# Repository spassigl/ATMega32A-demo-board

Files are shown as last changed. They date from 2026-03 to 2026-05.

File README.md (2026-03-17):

# ATMega32A demo board
An ATMega32A demo board with exposed GPIO pins, LEDs, tactile switches and a buzzer

## The project
This is a simple ATMega32A board that I used to test some ideas for a bigger project. 
It's a small factor pcb - 88x43mm - with the following features:
- ATMega32A clocked at 16MHz
- 4 layer stackup
- USB-C conneector for power and, with a booloader like urboot, for firmware updates and serial communication. 
- ISP 6-pin connector to flash bootloader or firmware (in case you don't want to use a booloader like urboot or optiboot)
- Power OR-ing - can have both ISP and USB connected
- All the unused GPIO pins are exposed via connectors on the side of the board
- Can use AREF for the ADC pins. AVCC connected via a low pass filter to reduce ADC noise
- SCL/SDA pull-up resistors can be enabled through solder jumpers
- Includes a buzzer, two LEDs, two tactile buttons
- Footprints are optimized for JLCPCB and "Basic" or "Preferred Extended" parts, to lower assembly costs

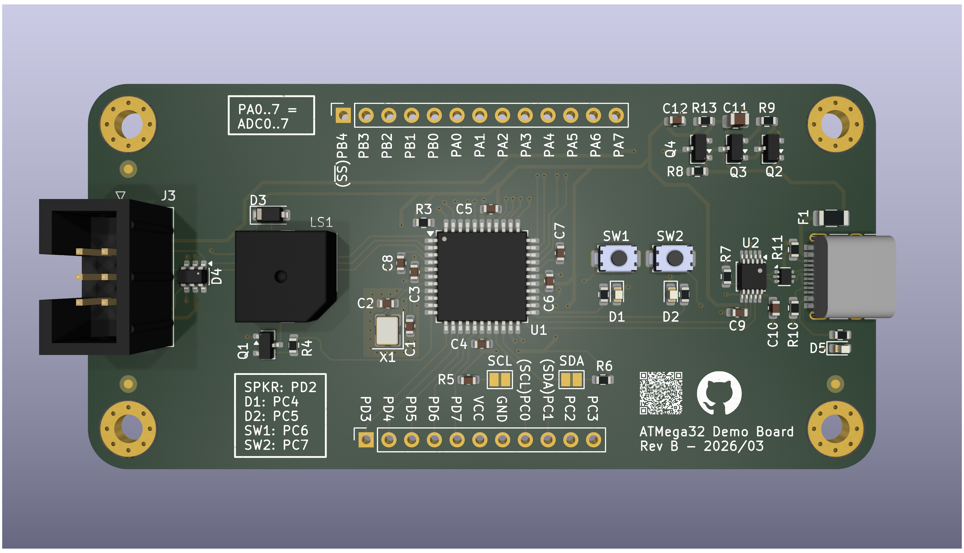
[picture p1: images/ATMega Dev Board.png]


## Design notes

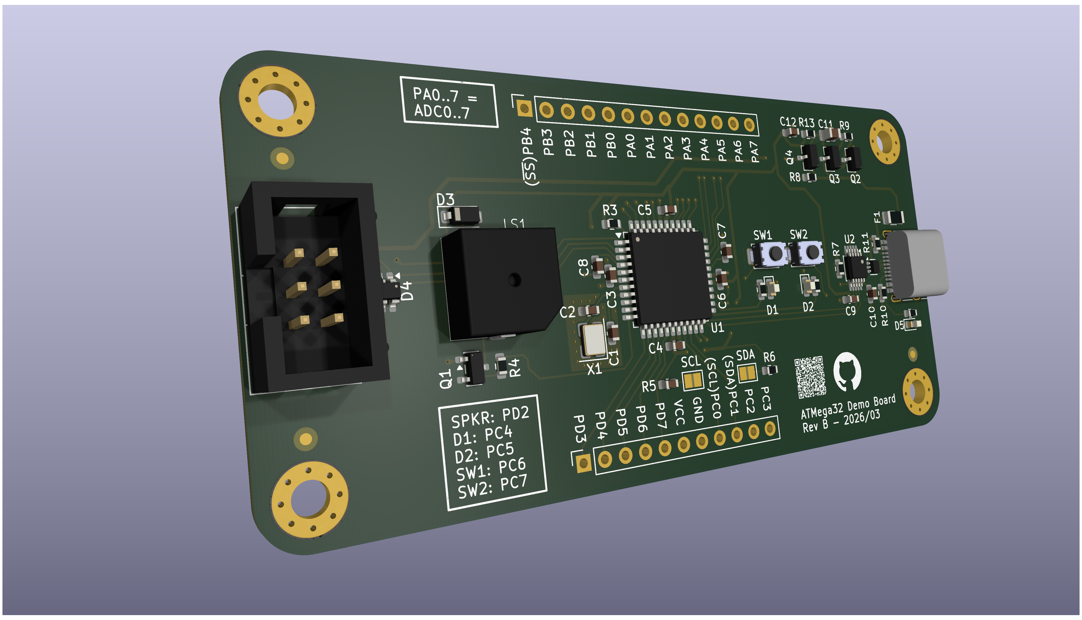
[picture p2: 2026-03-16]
images/ATMega Dev Board 3.png

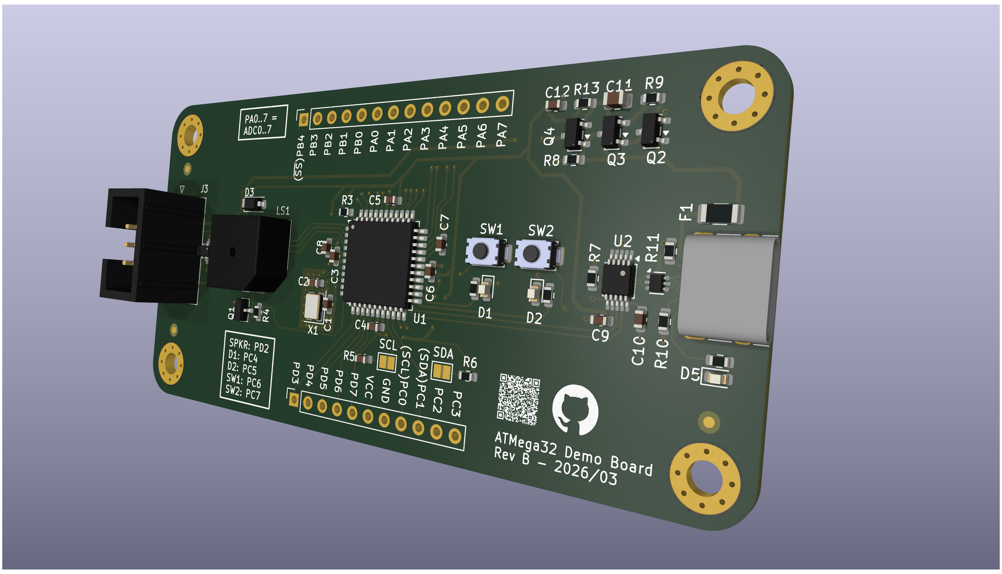
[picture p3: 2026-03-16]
images/ATMega Dev Board 2.png

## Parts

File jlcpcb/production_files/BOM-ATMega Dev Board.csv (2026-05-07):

Comment | Designator | Footprint | LCSC | Quantity
0.1u | C10,C12,C13,C3,C4,C5,C6,C7,C8,C9 | C_0603_1608Metric | C14663 | 10
0R | R13 | R_0603_1608Metric | C21189 | 1
10k | R3 | R_0603_1608Metric | C25804 | 1
10u | C11 | C_0805_2012Metric | C15850 | 1
10uH | L1 | L_0805_2012Metric | C2909263 | 1
16MHz | X1 | Crystal_SMD_3225-4Pin_3.2x2.5mm | C13738 | 1
1A | F1 | Fuse_1206_3216Metric | C69688 | 1
1N4001 | D3 | D_SOD-123 | C7462829 | 1
1k | R4 | R_0603_1608Metric | C21190 | 1
22p | C1,C2 | C_0603_1608Metric | C1653 | 2
2N7002 | Q2 | SOT-23 | C8545 | 1
330k | R8,R9 | R_0603_1608Metric | C23137 | 2
4k7 | R7 | R_0603_1608Metric | C23162 | 1
510 | R1,R12,R2 | R_0603_1608Metric | C23193 | 3
5k1 | R10,R11,R5,R6 | R_0603_1608Metric | C23186 | 4
ATmega32A-A | U1 | TQFP-44_10x10mm_P0.8mm | C5659 | 1
CH340X | U2 | MSOP-10_3x3mm_P0.5mm | C84681 | 1
HL6042 | Q3,Q4 | SOT-23 | C28646264 | 2
LED | D1,D2,D5 | LED_0603_1608Metric | C2286 | 3
S8050 | Q1 | SOT-23 | C2146 | 1
SPI header | J3 | IDC-Header_2x03_P2.54mm_Vertical | C492441 | 1
SRV05 | D4 | SOT-23-6 | C85364 | 1
SW_SPST | SW1,SW2 | Switch_TS-1088-AR02016 | C720477 | 2
Speaker | LS1 | Buzzer_MLT-9650 | C96127 | 1
USB-C_31-M-12 | J4 | USB_C_Receptacle_HRO_TYPE-C-31-M-12 | C165948 | 1
USBLC6-2P6 | U3 | SOT-666 | C15999 | 1

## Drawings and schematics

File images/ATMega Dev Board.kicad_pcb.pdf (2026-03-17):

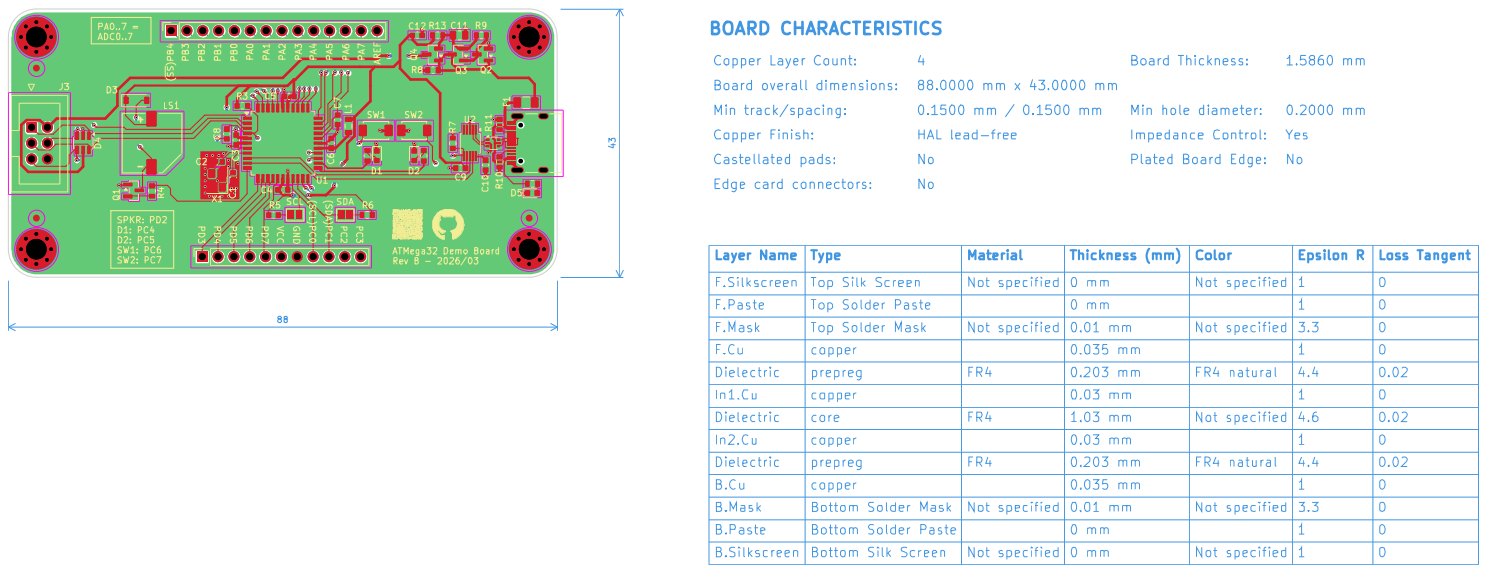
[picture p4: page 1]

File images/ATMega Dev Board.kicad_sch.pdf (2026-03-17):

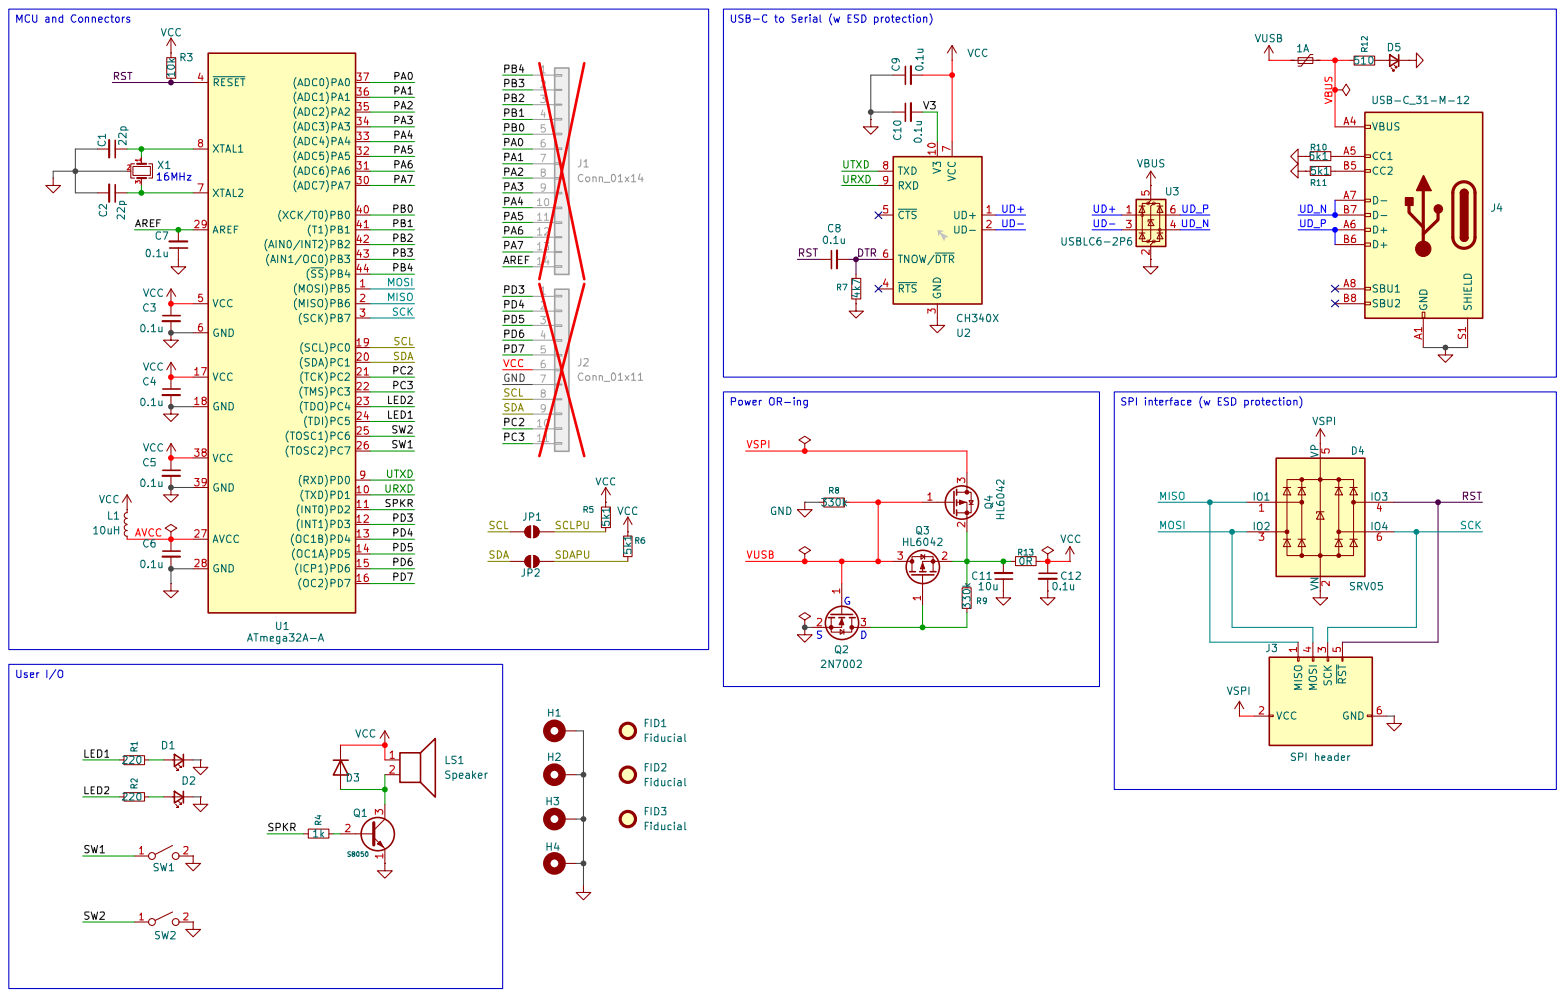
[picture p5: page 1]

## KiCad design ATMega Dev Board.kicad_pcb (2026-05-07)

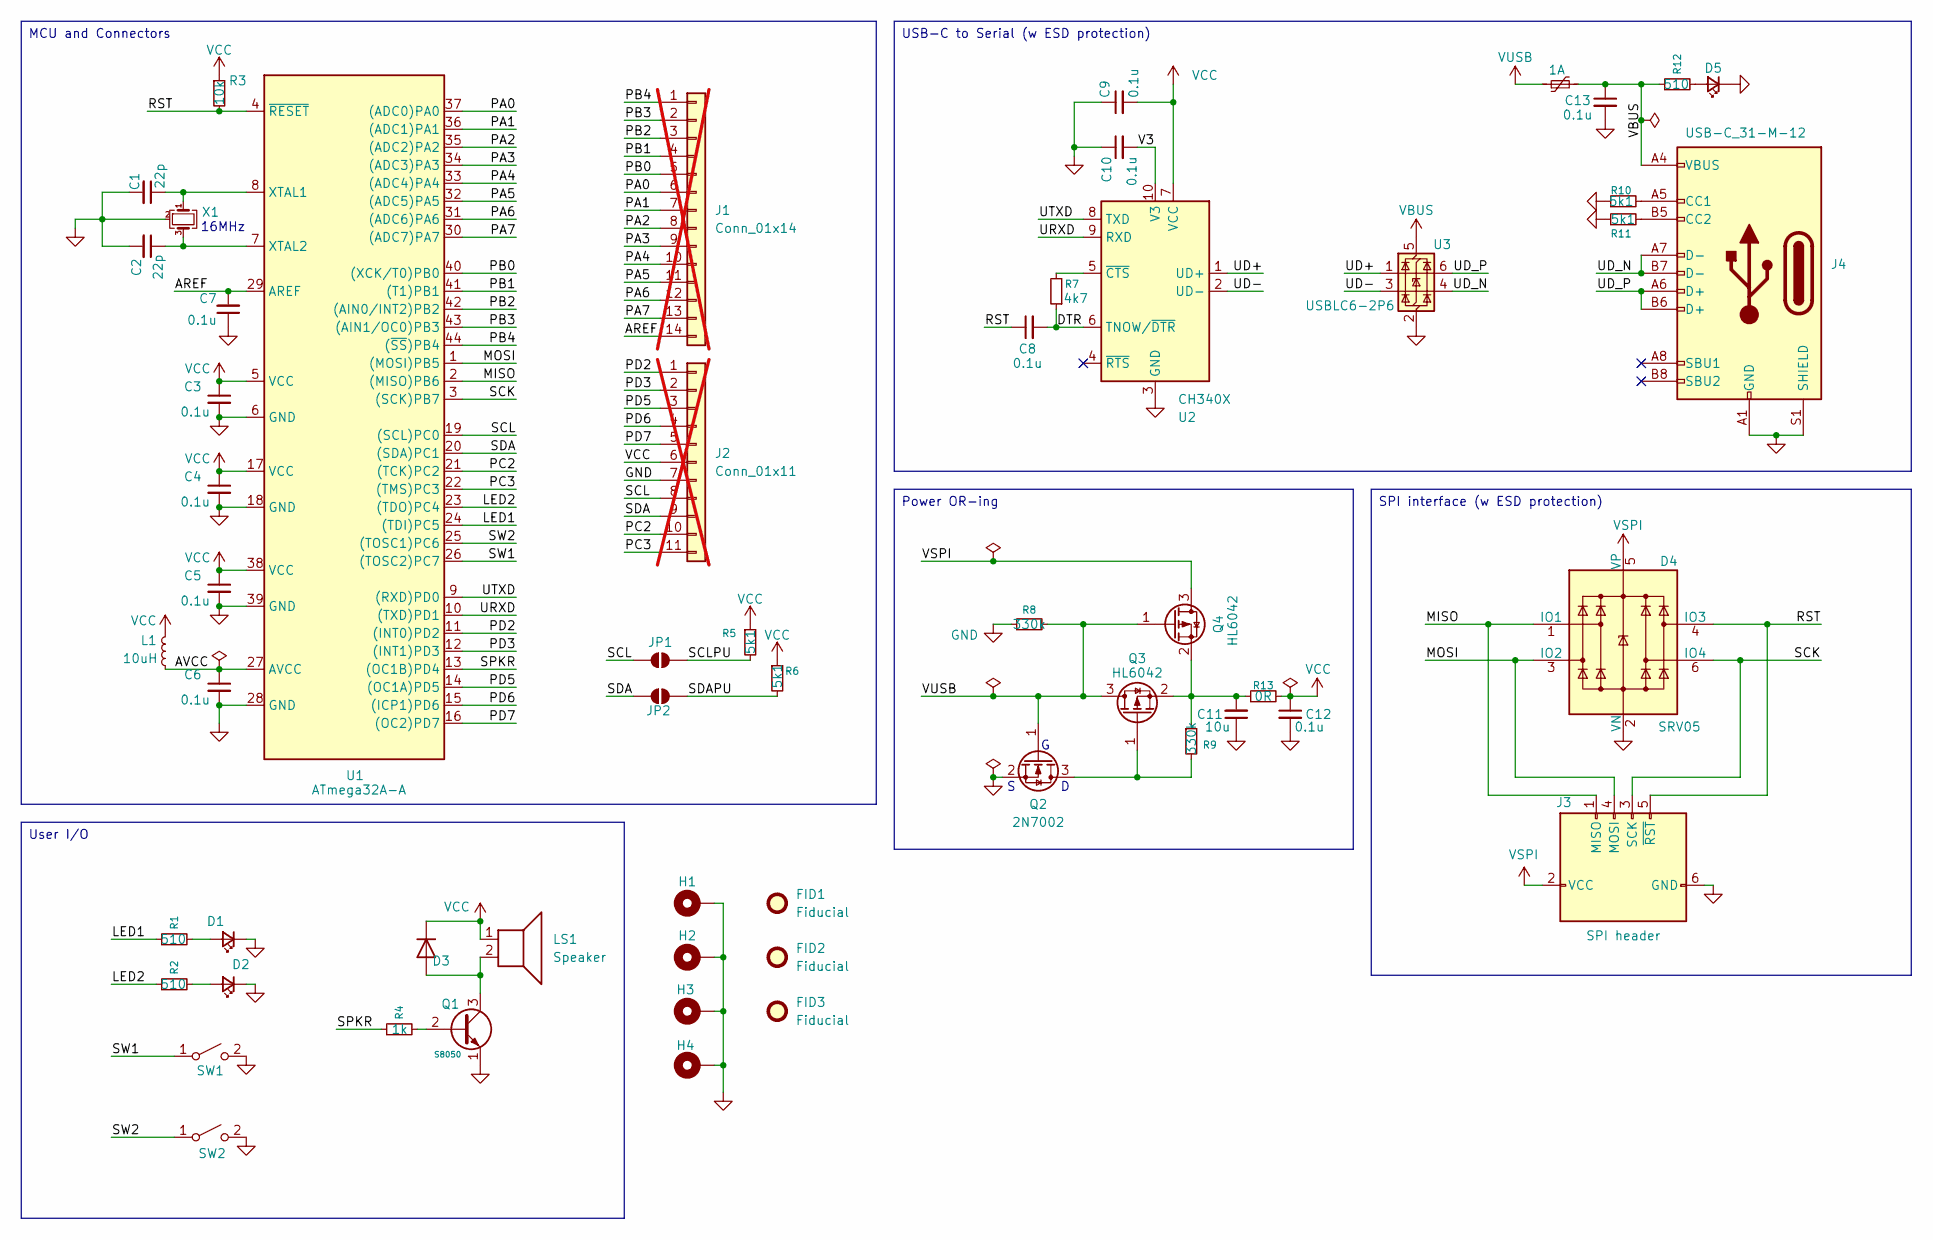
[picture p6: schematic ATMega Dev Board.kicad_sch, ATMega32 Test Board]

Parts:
C1, C2: 22p; C_0603_1608Metric; LCSC C1653
C3, C4, C5, C6, C7, C8, C9, C10, C12, C13: 0.1u; C_0603_1608Metric; LCSC C14663
C11: 10u; C_0805_2012Metric; LCSC C15850
D1, D2, D5: LED; LED_0603_1608Metric; LCSC C2286
D3: 1N4001; D_SOD-123; LCSC C7462829
D4: SRV05; SOT-23-6; LCSC C85364
F1: 1A; Fuse_1206_3216Metric; LCSC C69688
FID1, FID2, FID3: Fiducial; Fiducial_1mm_Mask2mm
H1, H2, H3, H4: MountingHole; MountingHole_3.2mm_M3_Pad_Via
J1: Conn_01x14; PinSocket_1x14_P2.54mm_Vertical; LCSC C2905420; not fitted
J2: Conn_01x11; PinSocket_1x11_P2.54mm_Vertical; LCSC C25503117; not fitted
J3: SPI header; IDC-Header_2x03_P2.54mm_Vertical; LCSC C492441
J4: USB-C_31-M-12; USB_C_Receptacle_HRO_TYPE-C-31-M-12; LCSC C165948
JP1, JP2: Jumper_2_Small_Open; SolderJumper-2_P1.3mm_Open_Pad1.0x1.5mm
L1: 10uH; L_0805_2012Metric; LCSC C2909263
LS1: Speaker; Buzzer_MLT-9650; LCSC C96127
Q1: S8050; SOT-23; LCSC C2146
Q2: 2N7002; SOT-23; LCSC C8545
Q3, Q4: HL6042; SOT-23; Part HL6042; LCSC C28646264
R1, R2, R12: 510; R_0603_1608Metric; LCSC C23193
R3: 10k; R_0603_1608Metric; LCSC C25804
R4: 1k; R_0603_1608Metric; LCSC C21190
R5: 5k1; C_0603_1608Metric; LCSC C23186
R6, R10, R11: 5k1; R_0603_1608Metric; LCSC C23186
R7: 4k7; R_0603_1608Metric; LCSC C23162
R8, R9: 330k; R_0603_1608Metric; LCSC C23137
R13: 0R; R_0603_1608Metric; LCSC C21189
SW1, SW2: SW_SPST; Switch_TS-1088-AR02016; LCSC C720477
U1: ATmega32A-A; TQFP-44_10x10mm_P0.8mm; LCSC C5659
U2: CH340X; MSOP-10_3x3mm_P0.5mm; LCSC C84681
U3: USBLC6-2P6; SOT-666; LCSC C15999
X1: 16MHz; Crystal_SMD_3225-4Pin_3.2x2.5mm; LCSC C13738

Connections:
/AREF: C7.2, J1.14, U1.29 (AREF)
/AVCC: C6.1, L1.2, U1.27 (AVCC)
/DTR: C8.2, R7.1, U2.6 (TNOW/~DTR)
/LED1: R1.1, U1.24 ((TDI)PC5)
/LED2: R2.1, U1.23 ((TDO)PC4)
/MISO: D4.1 (IO1), J3.1 (MISO), U1.2 ((MISO)PB6)
/MOSI: D4.3 (IO2), J3.4 (MOSI), U1.1 ((MOSI)PB5)
/PA0: J1.6, U1.37 ((ADC0)PA0)
/PA1: J1.7, U1.36 ((ADC1)PA1)
/PA2: J1.8, U1.35 ((ADC2)PA2)
/PA3: J1.9, U1.34 ((ADC3)PA3)
/PA4: J1.10, U1.33 ((ADC4)PA4)
/PA5: J1.11, U1.32 ((ADC5)PA5)
/PA6: J1.12, U1.31 ((ADC6)PA6)
/PA7: J1.13, U1.30 ((ADC7)PA7)
/PB0: J1.5, U1.40 ((XCK/T0)PB0)
/PB1: J1.4, U1.41 ((T1)PB1)
/PB2: J1.3, U1.42 ((AIN0/INT2)PB2)
/PB3: J1.2, U1.43 ((AIN1/OC0)PB3)
/PB4: J1.1, U1.44 ((~SS)PB4)
/PC2: J2.10, U1.21 ((TCK)PC2)
/PC3: J2.11, U1.22 ((TMS)PC3)
/PD2: J2.1, U1.11 ((INT0)PD2)
/PD3: J2.2, U1.12 ((INT1)PD3)
/PD5: J2.3, U1.14 ((OC1A)PD5)
/PD6: J2.4, U1.15 ((ICP1)PD6)
/PD7: J2.5, U1.16 ((OC2)PD7)
/RST: C8.1, D4.4 (IO3), J3.5 (~RST), R3.2, U1.4 (~RESET)
/SCK: D4.6 (IO4), J3.3 (SCK), U1.3 ((SCK)PB7)
/SCL: J2.8, JP1.1 (A), U1.19 ((SCL)PC0)
/SCLPU: JP1.2 (B), R5.2
/SDA: J2.9, JP2.1 (A), U1.20 ((SDA)PC1)
/SDAPU: JP2.2 (B), R6.2
/SPKR: R4.1, U1.13 ((OC1B)PD4)
/SW1: SW1.1 (A), U1.26 ((TOSC2)PC7)
/SW2: SW2.1 (A), U1.25 ((TOSC1)PC6)
/UD+: U2.1 (UD+), U3.1 (I/O1)
/UD-: U2.2 (UD-), U3.3 (I/O2)
/UD_N: J4.A7 (D-), J4.B7 (D-), U3.4 (I/O2)
/UD_P: J4.A6 (D+), J4.B6 (D+), U3.6 (I/O1)
/URXD: U1.10 ((TXD)PD1), U2.9 (RXD)
/UTXD: U1.9 ((RXD)PD0), U2.8 (TXD)
/V3: C10.2, U2.10 (V3)
GND: C1.2, C2.2, C3.2, C4.2, C5.2, C6.2, C7.1, C9.1, C10.1, C11.1, C12.2, C13.2, D1.1 (K), D2.1 (K), D4.2 (VN), D5.1 (K), H1.1 (1_1), H2.1 (1_1), H3.1 (1_1), H4.1 (1_1), J2.7, J3.6 (GND), J4.A1 (GND), J4.A12 (GND), J4.B1 (GND), J4.B12 (GND), J4.S1 (SHIELD), Q1.1 (E), Q2.2 (S), R8.1, R10.1, R11.1, SW1.2 (B), SW2.2 (B), U1.6 (GND), U1.18 (GND), U1.28 (GND), U1.39 (GND), U2.3 (GND), U3.2 (GND), X1.2 (G), X1.4 (G)
unnamed: D1.2 (A), R1.2
unnamed: D2.2 (A), R2.2
unnamed: D3.2 (A), LS1.2, Q1.3 (C)
unnamed: D5.2 (A), R12.2
unnamed: J4.A5 (CC1), R10.2
unnamed: J4.B5 (CC2), R11.2
unnamed: Q1.2 (B), R4.2
unnamed: Q2.3 (D), Q3.1 (G), R9.2
unnamed: C11.2, Q3.2 (S), Q4.2 (S), R9.1, R13.1
unnamed: C1.1, U1.8 (XTAL1), X1.1
unnamed: C2.1, U1.7 (XTAL2), X1.3
unnamed: R7.2, U2.5 (~CTS)
VBUS: C13.1, F1.2, J4.A4 (VBUS), J4.A9 (VBUS), J4.B4 (VBUS), J4.B9 (VBUS), R12.1, U3.5 (VBUS)
VCC: C3.1, C4.1, C5.1, C9.2, C12.1, D3.1 (K), J2.6, L1.1, LS1.1, R3.1, R5.1, R6.1, R13.2, U1.5 (VCC), U1.17 (VCC), U1.38 (VCC), U2.7 (VCC)
VSPI: D4.5 (VP), J3.2 (VCC), Q4.3 (D)
VUSB: F1.1, Q2.1 (G), Q3.3 (D), Q4.1 (G), R8.2

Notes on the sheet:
16MHz
SPI interface (w ESD protection)
USB-C to Serial (w ESD protection)
User I/O
Power OR-ing
MCU and Connectors

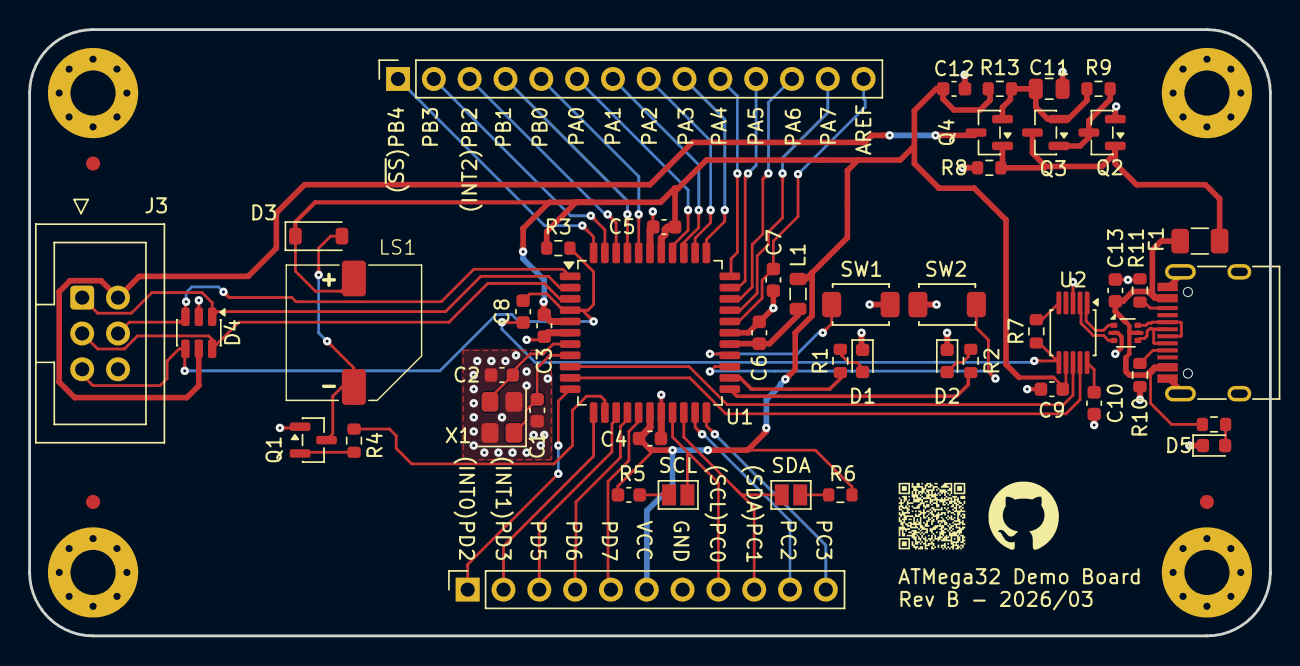
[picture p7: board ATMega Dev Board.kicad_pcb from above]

Board: 4 copper layers, 88.0 x 43.0 mm, 57 parts (0 on the bottom side), 60 nets.

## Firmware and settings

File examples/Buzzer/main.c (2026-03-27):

#include <avr/io.h>
#include <avr/interrupt.h>
#include <util/delay.h>
#include "buzzer.h"

int main(void) {

    buzzer_init();
    sei(); // Global interrupts MUST be on

    while (1) {
        buzzer_start_tick(25); // Start the beep
        // This delay represents your main code running.
        // The buzzer is handled entirely by the Timer2 ISR now.
        _delay_ms(1000); 
    }
}

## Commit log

2026-03-04 Improved VCC routing
    [ATMega Dev Board.kicad_pcb, ATMega Dev Board.kicad_sch]
2026-03-04 Small footprint changes
    [ATMega Dev Board.kicad_pcb]
2026-03-04 Better traces
    [ATMega Dev Board.kicad_pcb, ATMega Dev Board.kicad_sch, BOM-ATMega Dev Board.csv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]
2026-03-07 Better layout
    [ATMega Dev Board.kicad_pcb, ATMega Dev Board.kicad_sch]
2026-03-07 Removed KiCad backup file
2026-03-08 updated production files
    [BOM-ATMega Dev Board.csv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]
2026-03-11 added mounting holes
    [ATMega Dev Board.kicad_pcb, ATMega Dev Board.kicad_sch]
2026-03-11 better layout and new components
    [ATMega Dev Board.kicad_pcb, ATMega Dev Board.kicad_sch, BOM-ATMega Dev Board.csv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]
2026-03-11 cosmetic changes
    [ATMega Dev Board.kicad_sch]
2026-03-12 better vbus power layout
    [ATMega Dev Board.kicad_pcb, ATMega Dev Board.kicad_sch, BOM-ATMega Dev Board.csv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]
2026-03-12 exposed VCC and GND
    [ATMega Dev Board.kicad_pcb, ATMega Dev Board.kicad_sch]
2026-03-12 tweaked XTAL traces
    [ATMega Dev Board.kicad_pcb]
2026-03-16 scl/sda pullups; better vcc filter
    [ATMega Dev Board.kicad_sch]
2026-03-16 Rev B layout
    [ATMega Dev Board.kicad_pcb]
2026-03-16 tweaked layout
    [ATMega Dev Board.kicad_pcb, ATMega Dev Board.kicad_sch, BOM-ATMega Dev Board.csv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]
2026-03-17 added ADC/AREF components
    [ATMega Dev Board.kicad_pcb, ATMega Dev Board.kicad_sch, BOM-ATMega Dev Board.csv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]
2026-03-17 changed part#t
    [ATMega Dev Board.kicad_sch]
2026-03-17 upgraded USB-C routing
    [ATMega Dev Board.kicad_pcb, BOM-ATMega Dev Board.csv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]
2026-03-17 tweaked silkscreen
    [ATMega Dev Board.kicad_pcb]
2026-03-17 added VBUS capacitor
    [ATMega Dev Board.kicad_pcb, ATMega Dev Board.kicad_sch, BOM-ATMega Dev Board.csv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]
2026-03-17 pdf version of schematic and pcb
2026-05-07 fixed CH340X DTR setup
    [ATMega Dev Board.kicad_pcb, ATMega Dev Board.kicad_sch, BOM-ATMega Dev Board.csv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]
